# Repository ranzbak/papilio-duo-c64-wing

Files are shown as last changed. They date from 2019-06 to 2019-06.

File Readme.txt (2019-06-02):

BPS6001 Computing Shield Manufacturing Package - Current Version 1.01

Special assembly instructions:
	-Use RED for the PCB color.
	-All Arduino Mega Header pins should be populated with Male headers on the bottom of the board.
	-There is a V-Score indicated on the dimension layer of this PCB. The board should be manufactured as a single PCB with both sides of the V-Score connected. The end user will snap away the V-Score if they wish to do so.

Partial DigiKey BOM Link (Seeed and Generic Parts not included):
	https://www.digikey.com/classic/RegisteredUser/BOMBillOfMaterials.aspx?path=1&exist=1&id=1859538

Test Plan Home Page:
	http://www.gadgetfactory.net/opmanuals/index.php?n=Main.ComputingShield

CHANGELOG
11/18/2014	Version 1.02
	-Fixed the location of audio jack's.

10/20/2014	Version 1.01
	-Fixed the PS/2 footprints
	-Rotated the whole design 180 degrees to put the connectors at the top of the board and easier to work with.
	-Added Get Started URL

7/30/2014 Version 1.0
	First release with V-Score.

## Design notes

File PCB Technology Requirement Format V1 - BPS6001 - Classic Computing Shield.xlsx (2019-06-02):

深圳矽递科技有限公司 Seeed Technology Inc.
PCB Technology Requirement Format
PCB Name & Version | BPS6001 Classic Computing Shield
PCB Material PCB板材： | (Rigid)FR－4 | Flex
PCB Size PCB大小： | cm mm inch | ( 4.7 ) × ( 2.2 )
PCB Layer PCB层数： | 2 | 4 | other:( )
Thickness PCB厚度： | 0.8mm | 1.2mm | other:( )
 | 1mm | 1.6mm
Copper Weight 铜厚： | 1oz | 2oz | other:( )
PCB Colour 阻焊颜色： | Green 绿色 | White 白色 | Black 黑色
 | Red 红色 | Blue 蓝色 | other:( )
Silkscreen 字符颜色： | White 白色 | Black 黑色 | other:( )
Pads Finished 焊盘喷镀： | (Hasl-lead free) 无铅喷锡 | (Hasl) 含铅喷锡 | (ENIG) 沉镍金
Via solder mask 阻焊覆盖： | solder mask cover 过孔盖油 | solder mask opening 过孔开窗
Minimum trace/space (mm) 最小线宽 | 10mil | Minimum hole size (mm) 最小孔径 | 15mil
Special requirements 特殊工艺： | Yes | There is a special V-Score on the board that lets end users break the board into two pieces. The board should be manufactured as one piece with a V-Score.
Comment:

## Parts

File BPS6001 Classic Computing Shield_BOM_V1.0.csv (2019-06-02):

Qty-1 | Part References | Value | Package | Mfg Part Num | Mfg Name | VID | Vendor Part Num | Description | Pkg Code | XREF
1 | GROVE1 |  | CONNECTOR_4P-LEADED-2.0 | ACC39145O | Seeed Studio | SD | ACC39145O | Seeed Universal Grove Connector | * | REF178
4 | LED1, LED2, LED3, LED4 |  | CHIPLED_0603 | LTST-C190GKT | LITE-ON INC (VA) | DK | 160-1183-1-ND | LED GREEN CLEAR 0603 SMD | 603 | REF176
1 | CFG1 |  | JP5Q | M20-9720545 | Harwin | DK | 952-1927-ND | 2X5POS DIL VERTICAL PIN HEADER | * | REF177
5 | S1, S2, S3, S4, S5 |  | EVQ-Q2 | PTS525SM10SMTR LFS | C&K Components | DK | CKN9104CT-ND | SWITCH TACTILE SPST-NO 0.05A 12V | * | REF119
5 | C3, C4, C5, C6, C7 | .1uF | 0805 | GRM21BR71E104KA01L | MURATA ELECTRONICS (VA) | DK | 490-1673-1-ND | CAP CER .1UF 25V 10% X7R 0805 | 805 | REF97
3 | R33, R37, R40 | 1K | 0603 | RMCF0603JT1K00 | StackPole | DK | RMCF0603JT1K00CT-ND | RES 1K OHM 1/10W 5% 0603 | 603 | REF140
3 | R32, R36, R41 | 2K | 0603 | RMCF0603JT2K00 | Stackpole | DK | RMCF0603JT2K00CT-ND | RES 2K OHM 1/10W 5% 0603 | 603 | REF172
4 | R22, R28, R45, R46 | 3.3K | 0603 | RMCF0603JT3K30 | Stackpole | DK | RMCF0603JT3K30CT-ND | RES 3.3K OHM 1/10W 5% 0603 | 603 | REF168
3 | R31, R35, R42 | 3.9K | 0603 | RMCF0603JT3K90 | Stackpole | DK | RMCF0603JT3K90CT-ND | RES 3.9K OHM 1/10W 5% 0603 | 603 | REF171
24 | R1, R2, R3, R4, R5, R6, R7, R8, R9, R10, R11, R12, R13, R14, R15, R16, R17, R18, R19, R20, R21, R23, R24, R25 | 47K | 0603 | RMCF0603JT47K0 | Stackpole | DK | RMCF0603JT47K0CT-ND | RES 47K OHM 1/10W 5% 0603 | 603 | REF167
2 | R29, R30 | 82.5 | 0603 | RMCF0603FT82R5 | Stackpole | DK | RMCF0603FT82R5CT-ND | RES 82.5 OHM 1/10W 1% 0603 | 603 | REF170
6 | R26, R27, R43, R44, R47, R48 | 390 | 0603 | RMCF0603JT390R | StackPole | DK | RMCF0603JT390RCT-ND | RES 390 OHM 1/10W 5% 0603 | 603 | REF141
3 | R34, R38, R39 | 510 | 0603 | RMCF0603JT510R | Stackpole | DK | RMCF0603JT510RCT-ND | RES 510 OHM 1/10W 5% 0603 | 603 | REF174
4 | C1, C2, C8, C9 | 4700pF | 0603 | C0603C472J5RACTU | Kemet | DK | 399-1088-1-ND | CAP CER 4700PF 50V 5% X7R 0603 - Audio cap | 603 | REF175
2 | AJ1, AJ2 | AUDIO-CONNECTOR-6P-SMD-3440030P1 | 6P-SMD-3.5 | 3440030P1 | Seeed Studio | SD | 3440030P1 | 6P-SMD-3.5 - Audio Connector | * | REF183
1 | H1 | Arduino Mega Header | AMEGA_SHIELD_NOANALOG | Arduino_Mega_Header | Generic | GN | N/A | 1x65 Male Pin Header .1 | * | REF185
2 | PS2_A, PS2_B | CON_PS/2 | PS/2 | MD-60S | CUI | DK | CP-2460-ND | CONN MINIDIN RECPT UNSHIELD 6POS - PS/2 | * | REF180
1 | IC1 | MAX3232CSE | SO16 | MAX3232ECDR | Texas Instruments | DK | 296-19851-1-ND | IC RS232 3V5.5V 15KVESD 16-SOIC - Max3232 | SO16 | REF184
1 | SD1 | MICROSD | MICROSD | 101-00660-68-6 | Amphenol | DK | 101-00660-68-6-1-ND | CONN MINI MICRO-SD 8PIN PCB GOLD - MicroSD | * | REF181
3 | JS1, JS2, SP1 | Serial Port | M09HP | 10090097-P094VLF | FCI | DK | 609-4003-ND | DSUB R/A US 9POS PIN - Serial Port | * | REF179
1 | X1 | VGA | HDF15H | 1-1734530-1 | TE Connectivity | DK | A35116-ND | CONN HD D-SUB RCPT R/A 15POS - VGA Connector | * | REF182

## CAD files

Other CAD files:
BPS6001 Classic Computing Shield-V1.0-3D-Model.skp

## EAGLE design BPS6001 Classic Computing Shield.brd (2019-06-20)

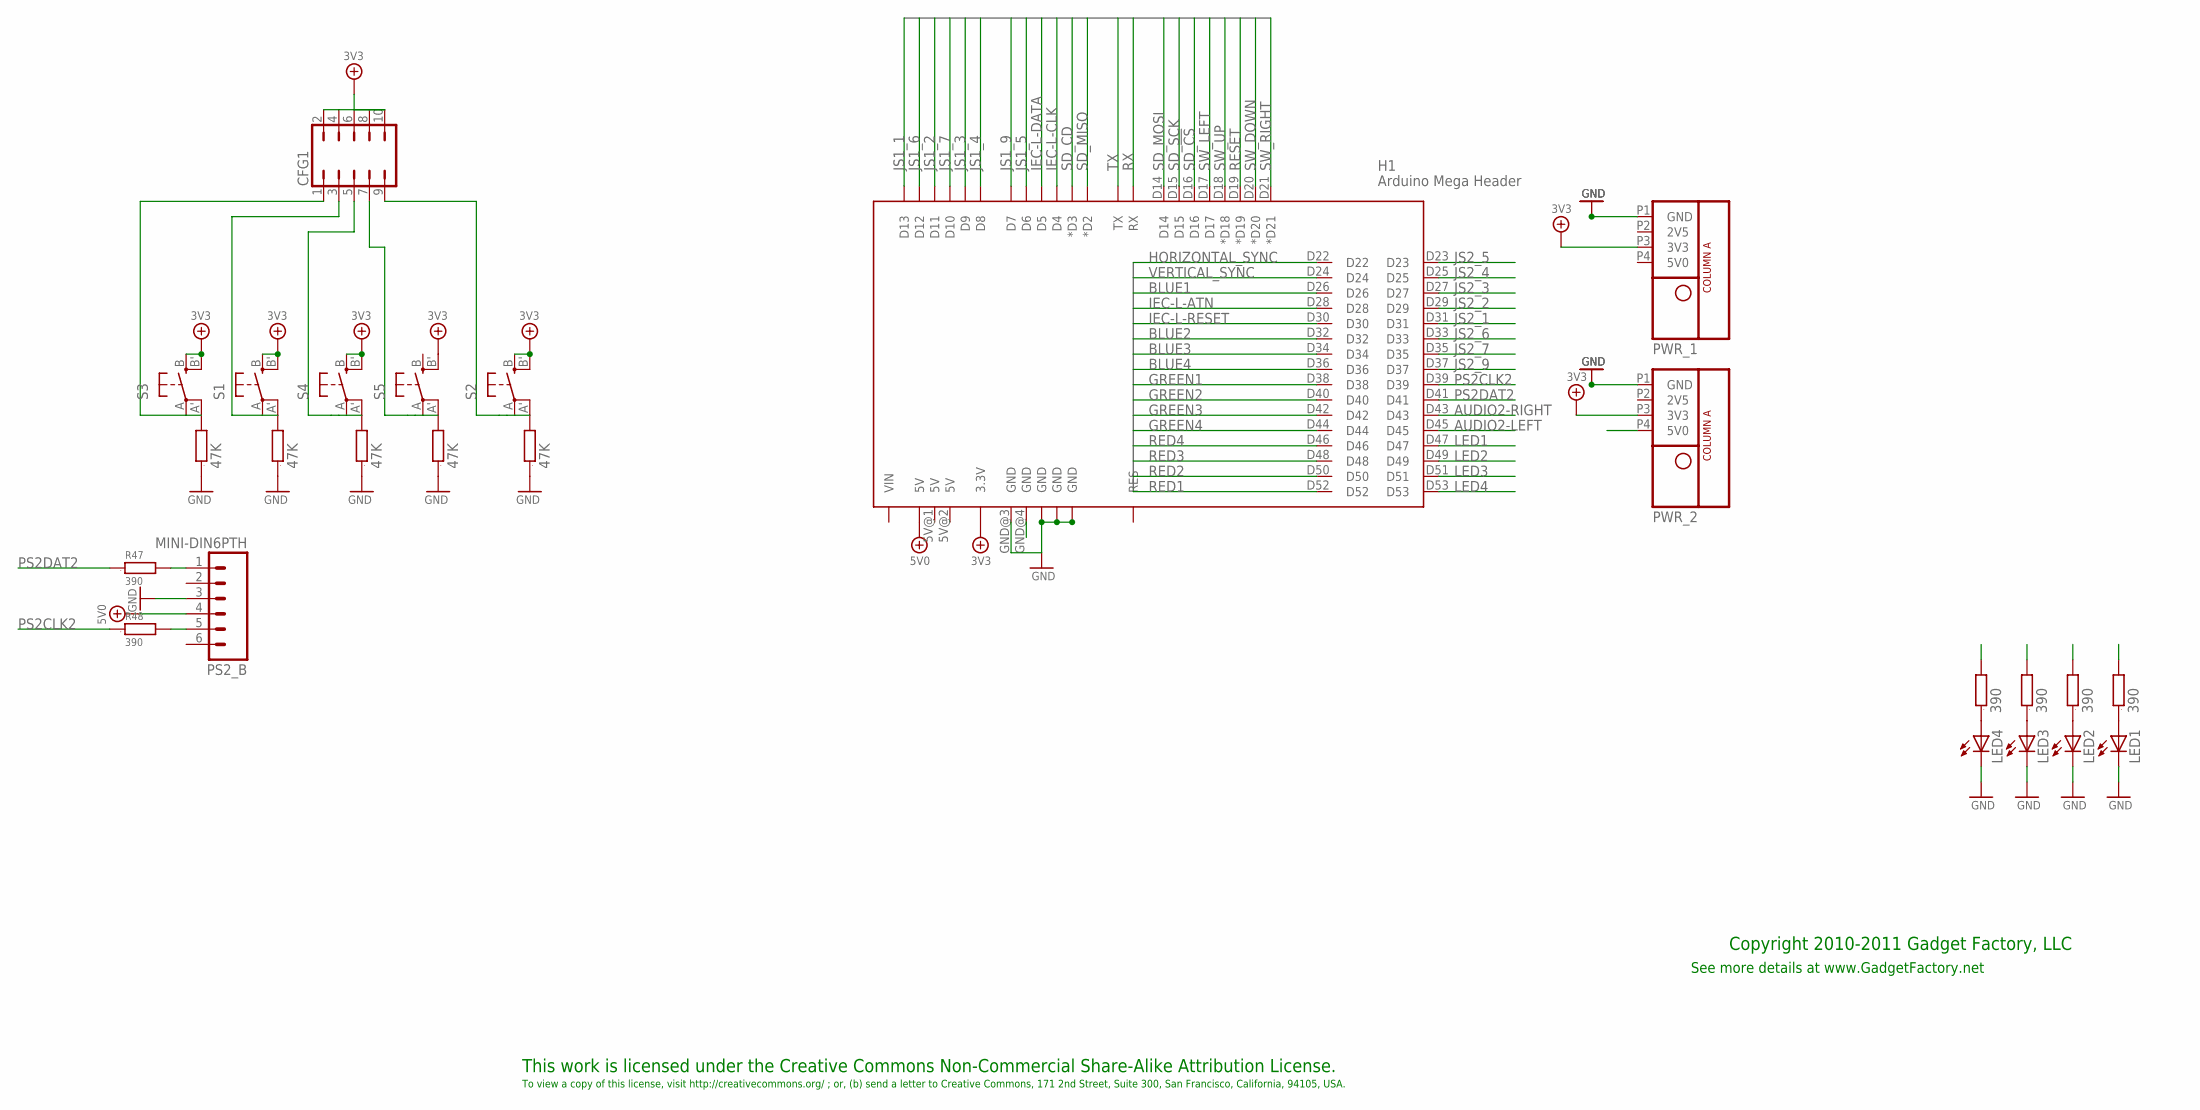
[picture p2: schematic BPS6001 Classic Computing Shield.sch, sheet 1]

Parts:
CFG1: JP5Q; PARTNO M20-9720545
H1: Arduino Mega Header; AMEGA_SHIELD_NOANALOG; PARTNO Arduino_Mega_Header
LED1, LED2, LED3, LED4: LEDCHIPLED_0603; CHIPLED_0603; PARTNO LTST-C190GKT
LOGO1: BUTTERFLY_LOGO
PS2_B: MINI-DIN6PTH; MINI-DIN6
PWR_1, PWR_2: POWER_ONLYNOTEXT; POWER_NO_TEXT
R9, R10, R11, R17, R18: 47K; 0603; PARTNO RMCF0603JT47K0
R26, R27, R43, R44, R47, R48: 390; 0603; PARTNO RMCF0603JT390R
S1, S2, S3, S4, S5: EVQQ2; EVQ-Q2; PARTNO PTS525SM10SMTR LFS

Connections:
3V3_PWR6: CFG1.2, CFG1.4, CFG1.6, CFG1.8, CFG1.10, H1.3.3V, S1.B (S), S1.B' (S1), S2.B (S), S2.B' (S1), S3.B (S), S3.B' (S1), S4.B (S), S4.B' (S1), S5.B' (S1); also elsewhere on the board
3V3_PWR7: PWR_2.P3 (3V3)
5V0: H1.5V@0 (5V); also elsewhere on the board
5V0_PS2: PS2_B.4, PWR_2.P4 (5V0)
AUDIO2-LEFT: H1.D45; also elsewhere on the board
AUDIO2-RIGHT: H1.D43; also elsewhere on the board
BLUE1: H1.D26; also elsewhere on the board
BLUE2: H1.D32; also elsewhere on the board
BLUE3: H1.D34; also elsewhere on the board
BLUE4: H1.D36; also elsewhere on the board
GND: H1.GND@0 (GND), H1.GND@1 (GND), H1.GND@2 (GND), H1.GND@3 (GND), R9.1, R10.1, R11.1, R17.1, R18.1; also elsewhere on the board
GREEN1: H1.D38; also elsewhere on the board
GREEN2: H1.D40; also elsewhere on the board
GREEN3: H1.D42; also elsewhere on the board
GREEN4: H1.D44; also elsewhere on the board
HORIZONTAL_SYNC: H1.D22; also elsewhere on the board
IEC-L-ATN: H1.D28; also elsewhere on the board
IEC-L-CLK: H1.D4; also elsewhere on the board
IEC-L-DATA: H1.D5; also elsewhere on the board
IEC-L-RESET: H1.D30; also elsewhere on the board
JOY_3V3: PWR_1.P3 (3V3); also elsewhere on the board
JOY_GND: H1.GND@4 (GND), LED1.C, LED2.C, LED3.C, LED4.C, PS2_B.3, PWR_1.P1 (GND), PWR_2.P1 (GND); also elsewhere on the board
JS1_1: H1.D13; also elsewhere on the board
JS1_2: H1.D11; also elsewhere on the board
JS1_3: H1.D9; also elsewhere on the board
JS1_4: H1.D8; also elsewhere on the board
JS1_5: H1.D6; also elsewhere on the board
JS1_6: H1.D12; also elsewhere on the board
JS1_7: H1.D10; also elsewhere on the board
JS1_9: H1.D7; also elsewhere on the board
JS2_1: H1.D31; also elsewhere on the board
JS2_2: H1.D29; also elsewhere on the board
JS2_3: H1.D27; also elsewhere on the board
JS2_4: H1.D25; also elsewhere on the board
JS2_5: H1.D23; also elsewhere on the board
JS2_6: H1.D33; also elsewhere on the board
JS2_7: H1.D35; also elsewhere on the board
JS2_9: H1.D37; also elsewhere on the board
LED1: H1.D47, R26.2
LED2: H1.D49, R27.2
LED3: H1.D51, R43.2
LED4: H1.D53, R44.2
unnamed: LED4.A, R44.1
unnamed: LED3.A, R43.1
unnamed: LED2.A, R27.1
unnamed: LED1.A, R26.1
unnamed: PS2_B.1, R47.2
unnamed: PS2_B.5, R48.2
PS2CLK2: H1.D39, R48.1
PS2DAT2: H1.D41, R47.1
RED1: H1.D52; also elsewhere on the board
RED2: H1.D50; also elsewhere on the board
RED3: H1.D48; also elsewhere on the board
RED4: H1.D46; also elsewhere on the board
RESET: CFG1.9, H1.D19 (*D19), R11.2, S2.A, S2.A' (P1)
RX: H1.RX
SD_!CS: H1.D16; also elsewhere on the board
SD_CD: H1.D3 (*D3); also elsewhere on the board
SD_MISO: H1.D2 (*D2); also elsewhere on the board
SD_MOSI: H1.D14; also elsewhere on the board
SD_SCK: H1.D15; also elsewhere on the board
SW_DOWN: CFG1.5, H1.D20 (*D20), R17.2, S4.A, S4.A' (P1)
SW_LEFT: CFG1.1, H1.D17, R9.2, S3.A, S3.A' (P1)
SW_RIGHT: CFG1.7, H1.D21 (*D21), R18.2, S5.A, S5.A' (P1)
SW_UP: CFG1.3, H1.D18 (*D18), R10.2, S1.A, S1.A' (P1)
TX: H1.TX
VERTICAL_SYNC: H1.D24; also elsewhere on the board

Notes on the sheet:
This work is licensed under the Creative Commons Non-Commercial Share-Alike Attribution License.
To view a copy of this license, visit http://creativecommons.org/ ; or, (b) send a letter to Creative Commons, 171 2nd Street, Suite 300, San Francisco, California, 94105, USA.
Copyright 2010-2011 Gadget Factory, LLC
See more details at www.GadgetFactory.net

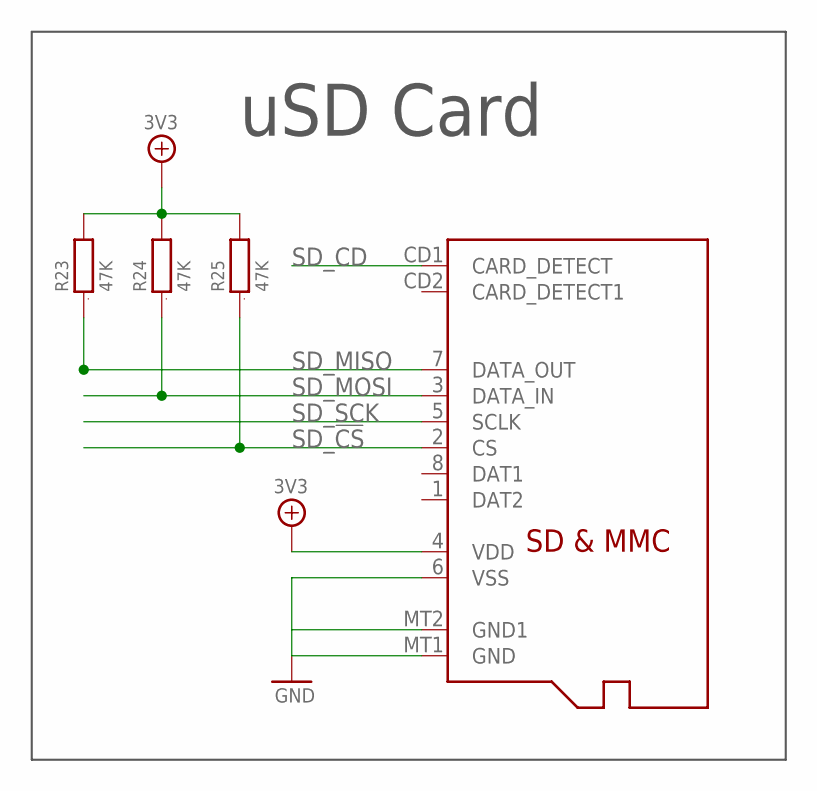
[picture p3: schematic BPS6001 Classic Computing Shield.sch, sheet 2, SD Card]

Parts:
R23, R24, R25: 47K; 0603; PARTNO RMCF0603JT47K0
SD1: MICROSD; PARTNO 101-00660-68-6

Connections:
3V3_PWR6: R23.2, R24.2, R25.2, SD1.4 (VDD); also elsewhere on the board
GND: SD1.6 (VSS), SD1.MT1 (GND), SD1.MT2 (GND1); also elsewhere on the board
SD_!CS: R25.1, SD1.2 (CS); also elsewhere on the board
SD_CD: SD1.CD1 (CARD_DETECT); also elsewhere on the board
SD_MISO: R23.1, SD1.7 (DATA_OUT); also elsewhere on the board
SD_MOSI: R24.1, SD1.3 (DATA_IN); also elsewhere on the board
SD_SCK: SD1.5 (SCLK); also elsewhere on the board

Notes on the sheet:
uSD Card

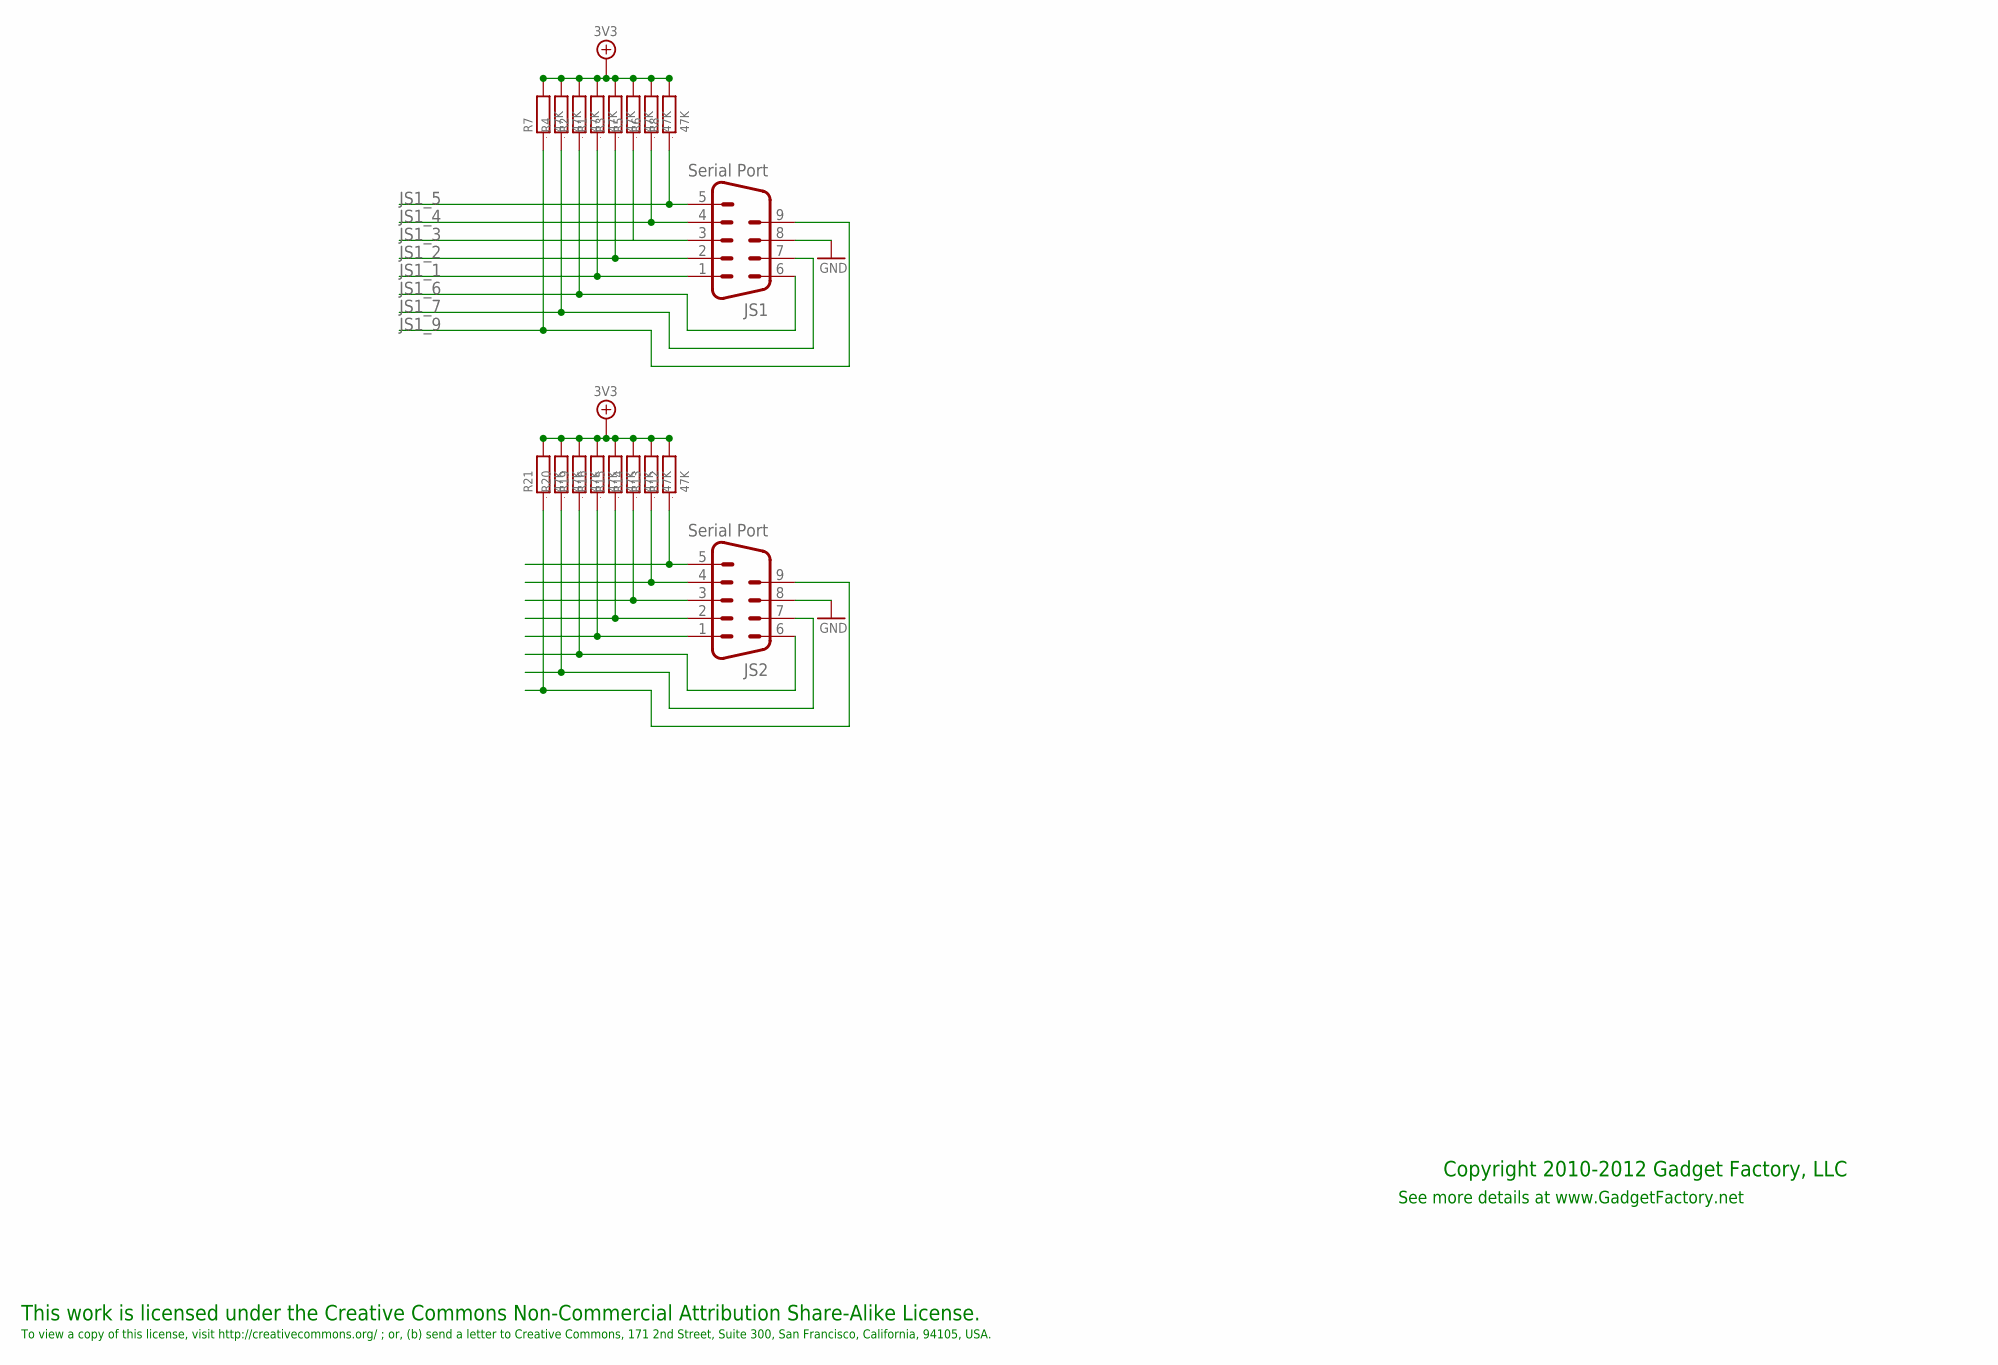
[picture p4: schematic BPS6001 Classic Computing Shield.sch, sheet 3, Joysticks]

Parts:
JS1, JS2: Serial Port; M09HP; PARTNO 10090097-P094VLF
R1, R2, R3, R4, R5, R6, R7, R8, R12, R13, R14, R15, R16, R19, R20, R21: 47K; 0603; PARTNO RMCF0603JT47K0

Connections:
3V3_PWR6: R1.2, R2.2, R3.2, R4.2, R5.2, R6.2, R7.2, R8.2; also elsewhere on the board
GND: JS1.8; also elsewhere on the board
JOY_3V3: R12.2, R13.2, R14.2, R15.2, R16.2, R19.2, R20.2, R21.2; also elsewhere on the board
JOY_GND: JS2.8; also elsewhere on the board
JS1_1: JS1.1, R1.1; also elsewhere on the board
JS1_2: JS1.2, R3.1; also elsewhere on the board
JS1_3: JS1.3, R5.1; also elsewhere on the board
JS1_4: JS1.4, R6.1; also elsewhere on the board
JS1_5: JS1.5, R8.1; also elsewhere on the board
JS1_6: JS1.6, R2.1; also elsewhere on the board
JS1_7: JS1.7, R4.1; also elsewhere on the board
JS1_9: JS1.9, R7.1; also elsewhere on the board
JS2_1: JS2.1, R16.1; also elsewhere on the board
JS2_2: JS2.2, R15.1; also elsewhere on the board
JS2_3: JS2.3, R14.1; also elsewhere on the board
JS2_4: JS2.4, R13.1; also elsewhere on the board
JS2_5: JS2.5, R12.1; also elsewhere on the board
JS2_6: JS2.6, R19.1; also elsewhere on the board
JS2_7: JS2.7, R20.1; also elsewhere on the board
JS2_9: JS2.9, R21.1; also elsewhere on the board

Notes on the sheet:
This work is licensed under the Creative Commons Non-Commercial Attribution Share-Alike License.
To view a copy of this license, visit http://creativecommons.org/ ; or, (b) send a letter to Creative Commons, 171 2nd Street, Suite 300, San Francisco, California, 94105, USA.
Copyright 2010-2012 Gadget Factory, LLC
See more details at www.GadgetFactory.net

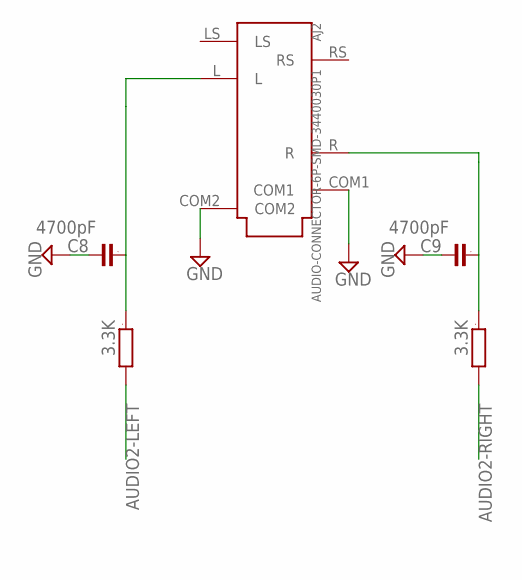
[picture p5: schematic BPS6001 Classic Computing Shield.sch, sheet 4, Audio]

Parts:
AJ2: AUDIO-CONNECTOR-6P-SMD-3440030P1; 6P-SMD-3.5; PARTNO 3440030P1
C8, C9: 4700pF; 0603; PARTNO C0603C472J5RACTU
R45, R46: 3.3K; 0603; PARTNO RMCF0603JT3K30

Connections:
AUDIO2-LEFT: R45.2; also elsewhere on the board
AUDIO2-RIGHT: R46.2; also elsewhere on the board
JOY_GND: AJ2.COM1, AJ2.COM2, C8.2, C9.2; also elsewhere on the board
unnamed: AJ2.L, C8.1, R45.1
unnamed: AJ2.R, C9.1, R46.1

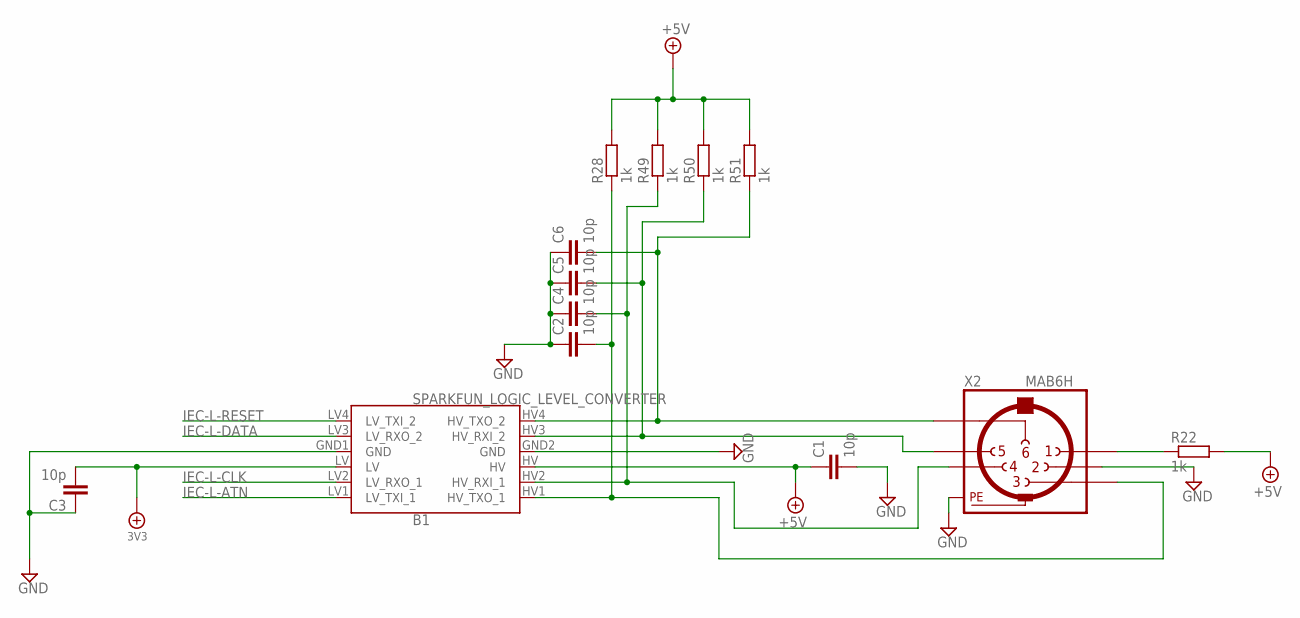
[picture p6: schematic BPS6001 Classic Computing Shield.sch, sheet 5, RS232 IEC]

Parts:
B1: SPARKFUN_LOGIC_LEVEL_CONVERTER
C1, C2, C3, C4, C5, C6: 10p; C0603
R22, R28, R49, R50, R51: 1k; R0603
X2: MAB6H

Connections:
3V3_PWR6: B1.LV, C3.2; also elsewhere on the board
5V0: B1.HV, C1.1, R22.2, R28.2, R49.2, R50.2, R51.2; also elsewhere on the board
GND: B1.GND1 (GND), B1.GND2 (GND), C1.2, C2.1, C3.1, C4.1, C5.1, C6.1, X2.2, X2.PE, X2.PE@ (PE); also elsewhere on the board
IEC-H-ATN: B1.HV1 (HV_TXO_1), C2.2, R28.1, X2.3
IEC-H-CLK: B1.HV2 (HV_RXI_1), C4.2, R49.1, X2.4
IEC-H-DATA: B1.HV3 (HV_RXI_2), C5.2, R50.1, X2.5
IEC-H-RESET: B1.HV4 (HV_TXO_2), C6.2, R51.1, X2.6
IEC-H-SRQ: R22.1, X2.1
IEC-L-ATN: B1.LV1 (LV_TXI_1); also elsewhere on the board
IEC-L-CLK: B1.LV2 (LV_RXO_1); also elsewhere on the board
IEC-L-DATA: B1.LV3 (LV_RXO_2); also elsewhere on the board
IEC-L-RESET: B1.LV4 (LV_TXI_2); also elsewhere on the board

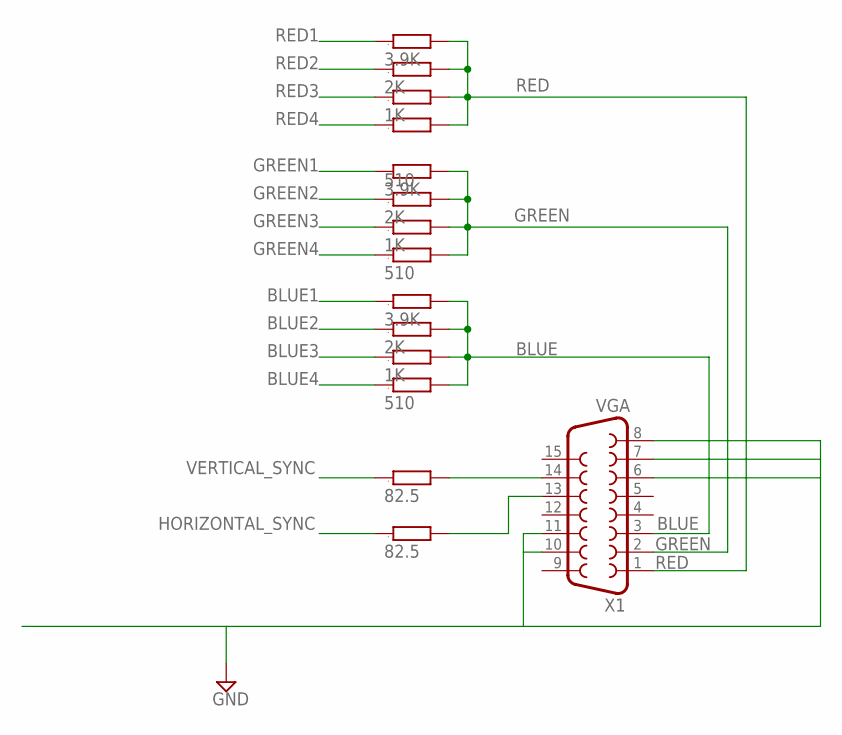
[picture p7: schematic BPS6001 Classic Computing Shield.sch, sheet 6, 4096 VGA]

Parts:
R29, R30: 82.5; 0603; PARTNO RMCF0603FT82R5
R31, R35, R42: 3.9K; 0603; PARTNO RMCF0603JT3K90
R32, R36, R41: 2K; 0603; PARTNO RMCF0603JT2K00
R33, R37, R40: 1K; 0603; PARTNO RMCF0603JT1K00
R34, R38, R39: 510; 0603; PARTNO RMCF0603JT510R
X1: VGA; HDF15H; PARTNO 1-1734530-1

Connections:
BLUE: R31.2, R32.2, R33.2, R34.2, X1.3
BLUE1: R31.1; also elsewhere on the board
BLUE2: R32.1; also elsewhere on the board
BLUE3: R33.1; also elsewhere on the board
BLUE4: R34.1; also elsewhere on the board
GND: X1.6, X1.7, X1.8, X1.10, X1.11; also elsewhere on the board
GREEN: R35.2, R36.2, R37.2, R38.2, X1.2
GREEN1: R35.1; also elsewhere on the board
GREEN2: R36.1; also elsewhere on the board
GREEN3: R37.1; also elsewhere on the board
GREEN4: R38.1; also elsewhere on the board
HORIZONTAL_SYNC: R29.1; also elsewhere on the board
unnamed: R29.2, X1.13
unnamed: R30.2, X1.14
RED: R39.2, R40.2, R41.2, R42.2, X1.1
RED1: R42.1; also elsewhere on the board
RED2: R41.1; also elsewhere on the board
RED3: R40.1; also elsewhere on the board
RED4: R39.1; also elsewhere on the board
VERTICAL_SYNC: R30.1; also elsewhere on the board

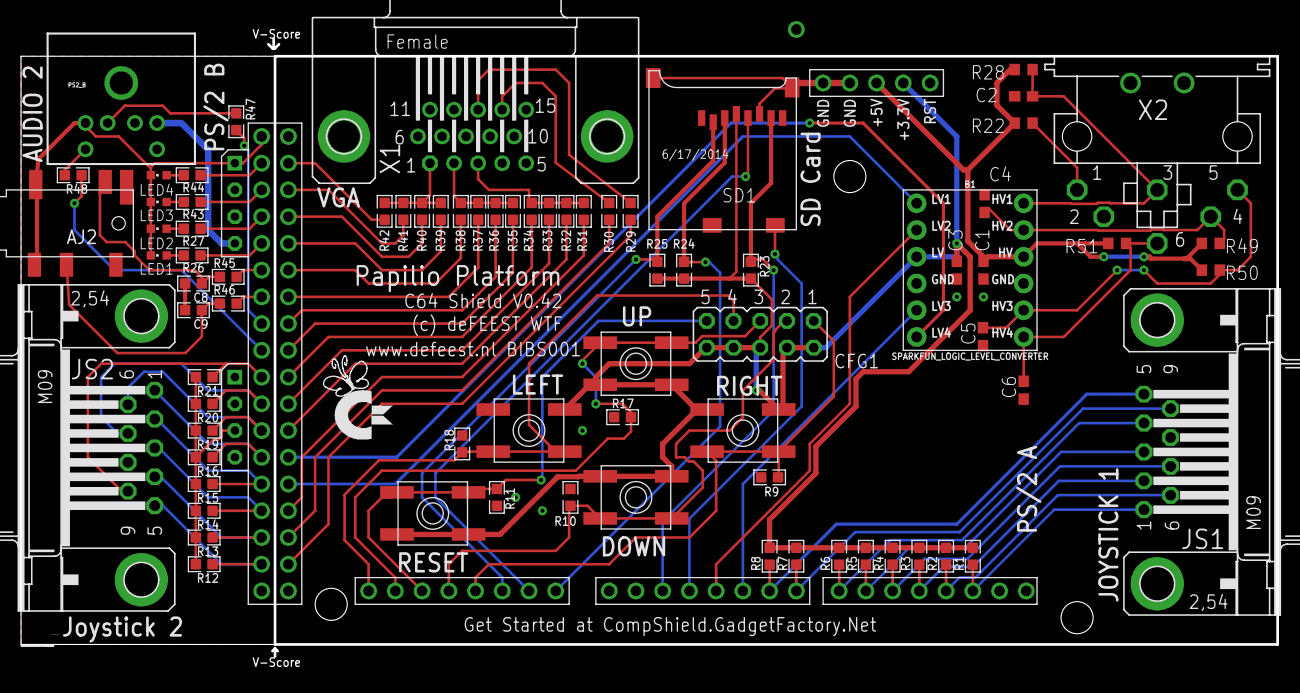
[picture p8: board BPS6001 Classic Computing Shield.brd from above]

Board: 2 copper layers, 119.4 x 58.7 mm, 84 parts (0 on the bottom side), 76 nets.

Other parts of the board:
U$1, U$2, U$3: STAND-OFF-TIGHT

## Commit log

2019-06-02 Removed the other wings in the original project.
    [16-bit-OV7670 mini Camera wing.brd, 16-bit-OV7670 mini Camera wing.sch, 16bit_Wing_Template.brd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]
2019-06-20 First outline of design moved to Eagle 9.
    [BPS6001 Classic Computing Shield.brd, BPS6001 Classic Computing Shield.sch]
2019-06-20 Fixed some issues, board is now without problems.
    [BPS6001 Classic Computing Shield.brd, BPS6001 Classic Computing Shield.sch]
2019-07-06 Added BOM file to the project.

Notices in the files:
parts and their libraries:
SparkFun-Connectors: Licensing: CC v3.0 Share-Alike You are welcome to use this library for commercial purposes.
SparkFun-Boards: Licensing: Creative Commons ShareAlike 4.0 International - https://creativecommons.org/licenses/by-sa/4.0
